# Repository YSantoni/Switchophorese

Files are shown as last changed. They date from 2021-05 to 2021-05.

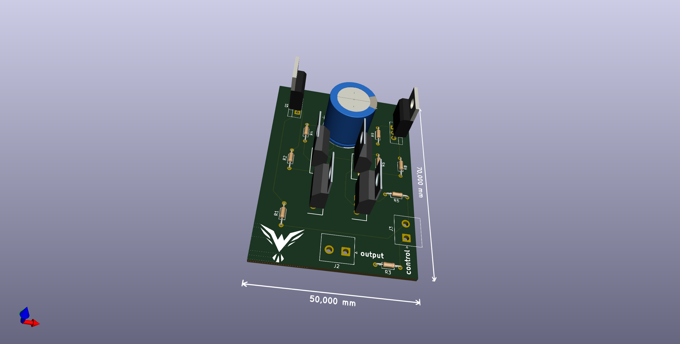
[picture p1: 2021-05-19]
Circuit/FullHBridge/3DFullHBridge.png

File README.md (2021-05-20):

# Switchophorese
An open source Field Inversion Gel Electrophoresis module, programmable via touchscreen.
Connect this module between your classic lab power supply and your gel tray.

This open source laboratory equipment is based on :

- Arduino mega
- Tft 2.8 lcd touch screen shield
- Mosfet full h-bridge circuit

Specs : suitable for gel electrophoresis or field inversion electrophoresis

- 40v to 200v
- max 6.5 amps
- 20ns switching time

Programmable elements :

- pre-heating timer
- runtime timer
- first pulse duration
- last pulse duration
- ratio forward/backward pulse
- linear or exponential time ramp

Libraries used :

https://github.com/prenticedavid/MCUFRIEND_kbv

https://github.com/adafruit/Adafruit_TouchScreen

102794269-6e10de80-43ab-11eb-8156-e7d295066625

group

**First screen** : Welcome screen, touch anywhere to begin.

**Second screen** : Set the duration for the pre-heating timer "Init" and the runtime timer "Run". Select hour, minute, or second and set it with "+" and "-" square, when done touch                 "OK" to go to the next screen.

**Third screen** : Set the duration of the first and last forward pulse of the run (minimum steps of 10ms). Set the duration of the backward pulse as a ratio of the forward pulse.
                You can choose linear or exponential to have the desired evolution of pulse duration during the run.

**Fourth screen** : The recap screen with all the parameters you have entered, when ready press "Begin".

**Fifth screen** : The run screen

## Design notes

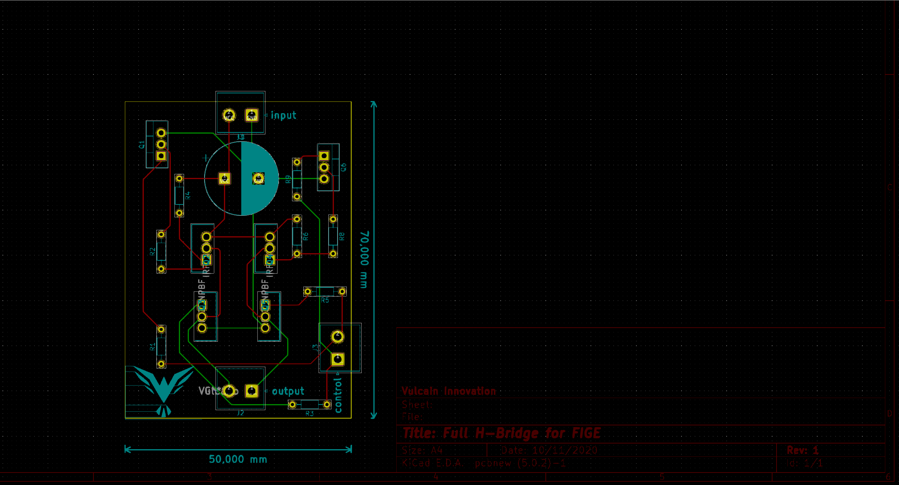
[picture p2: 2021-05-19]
Circuit/FullHBridge/CaptureFullHBridge.PNG

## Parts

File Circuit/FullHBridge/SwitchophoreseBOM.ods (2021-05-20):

Switchophorese FIGE
Total | $0.00
Part Number | Item Description | Number of items | Retailer | Price per item | Price for number of items | Link
1 | Arduino mega 2560 | 1
2 | TFT 2.8 lcd touchscreen shield | 1
3 | 9V DC charger | 1
4 | Electrolytic Capacitor 100uF | 1
5 | Resistor 1K | 2
6 | Resistor 2.2K | 2
7 | Resistor 10K | 2
8 | Resistor 90K | 2
9 | Transistor NPN BJT TIP41 | 2
10 | Transistor MOSFET NPN IRF630 | 2
11 | Transistor MOSFET PNP IRF9630 | 2
12 | Banana plug male (input) | 2
13 | Banana plug female (output) | 2

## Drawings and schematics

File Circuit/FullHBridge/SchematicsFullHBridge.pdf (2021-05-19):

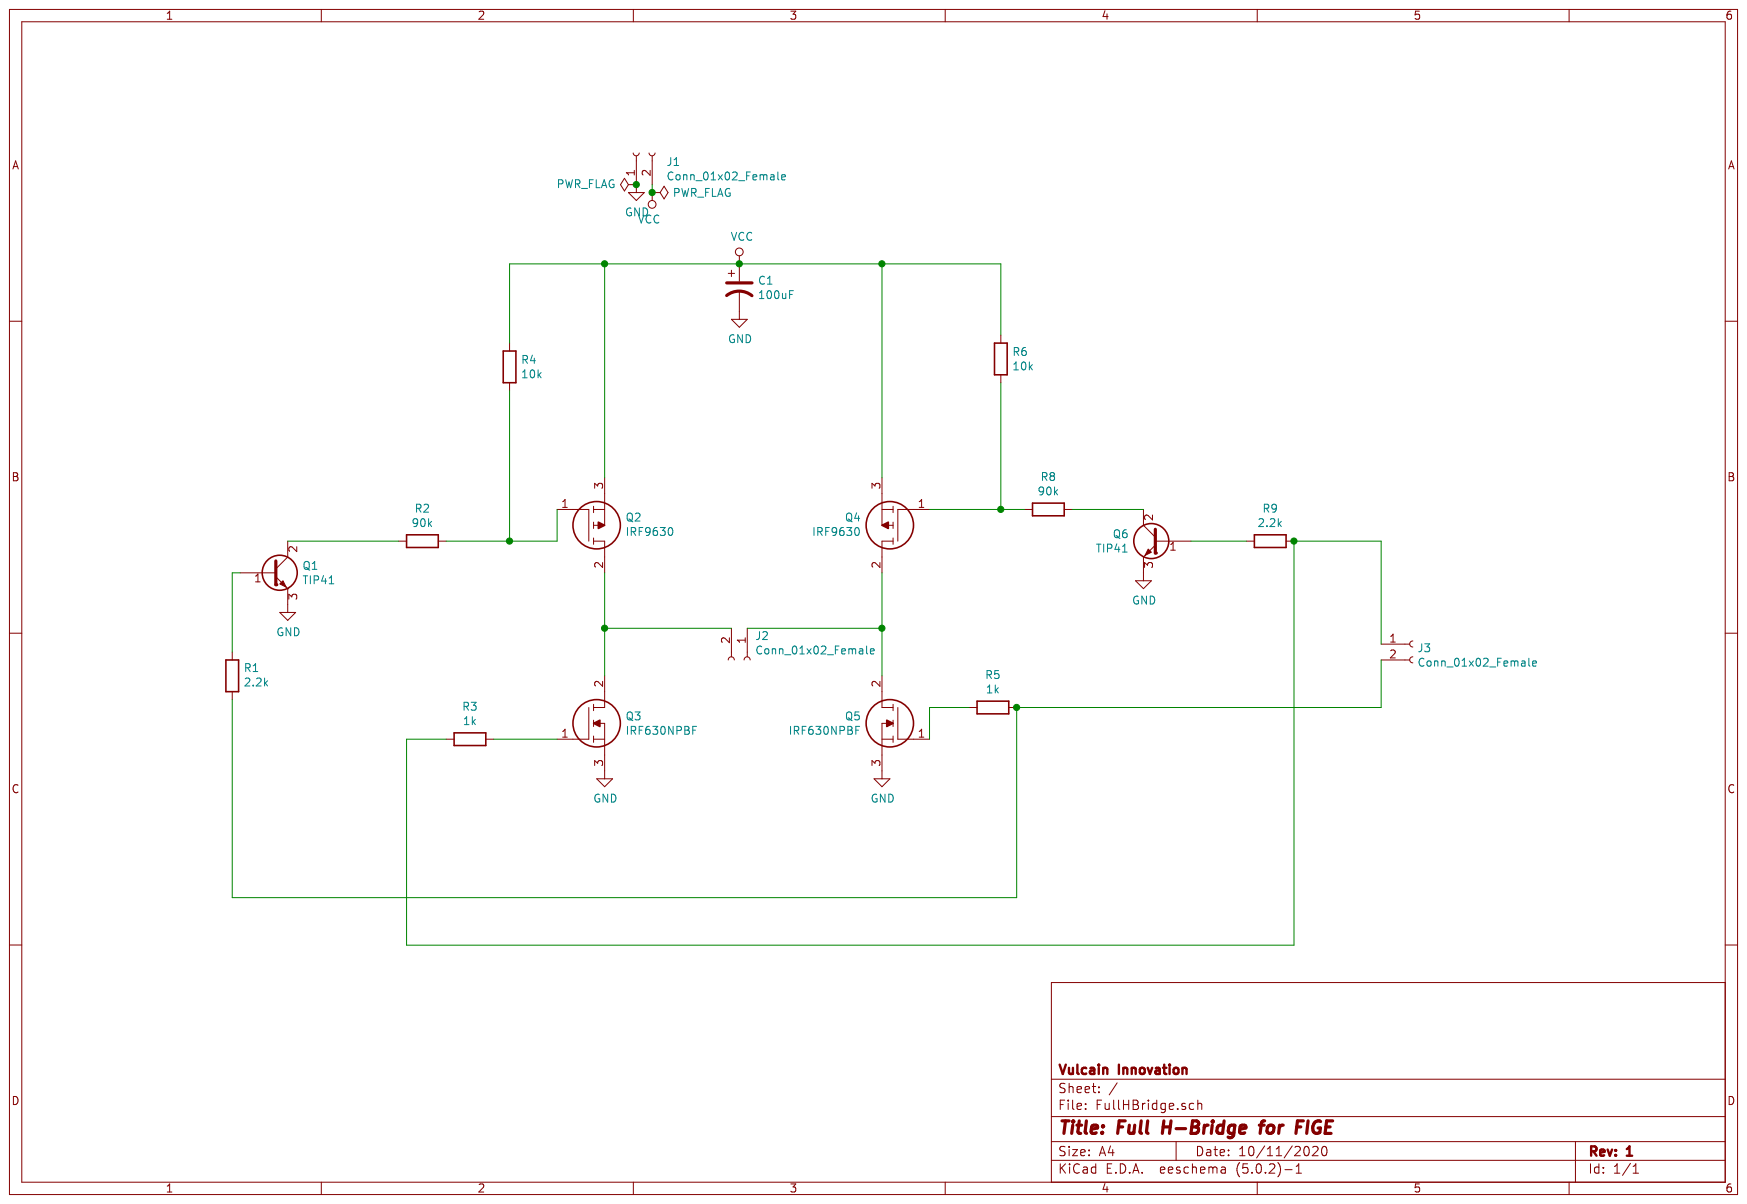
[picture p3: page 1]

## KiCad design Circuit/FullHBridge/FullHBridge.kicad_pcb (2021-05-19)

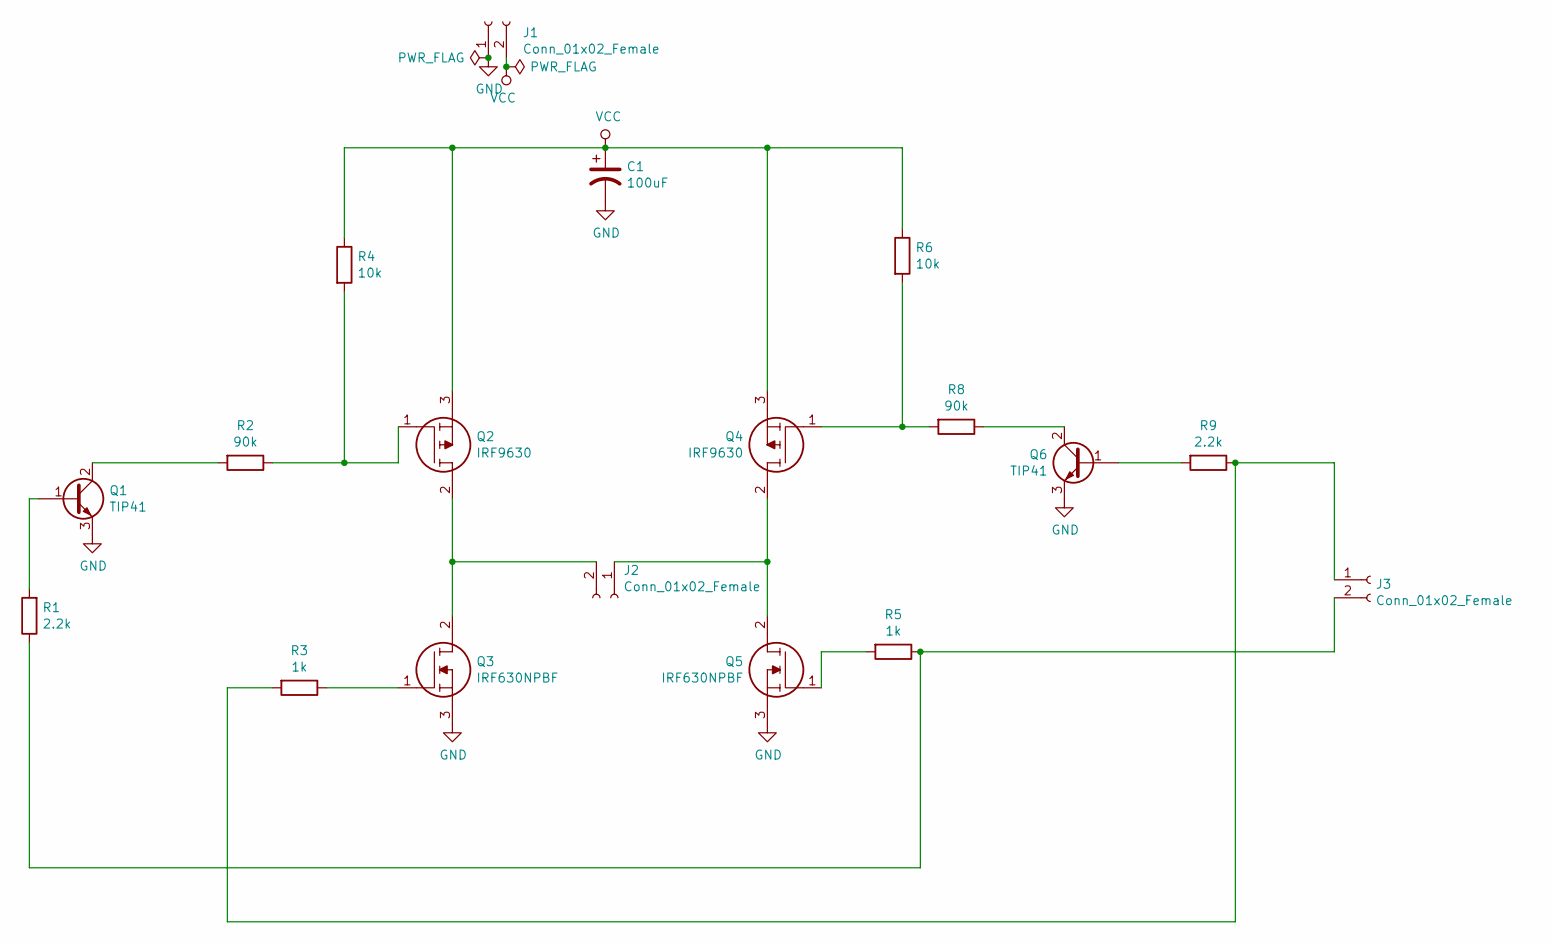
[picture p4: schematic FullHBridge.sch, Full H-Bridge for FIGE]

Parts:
C1: 100uF; CP_Radial_D16.0mm_P7.50mm
J1, J2, J3: Conn_01x02_Female; JST_NV_B02P-NV_1x02_P5.00mm_Vertical
Q1, Q6: TIP41; TO-220-3_Vertical
Q2, Q4: IRF9630; TO254P465X1024X2050-3P; Manufacturer_Part_Number IRF9630; Mouser Part Number 844-IRF9630
Q3, Q5: IRF630NPBF; TO254P469X1042X1967-3P; Manufacturer_Part_Number IRF630NPBF; Mouser Part Number 942-IRF630NPBF
R1, R9: 2.2k; R_Axial_DIN0204_L3.6mm_D1.6mm_P7.62mm_Horizontal
R2, R8: 90k; R_Axial_DIN0204_L3.6mm_D1.6mm_P7.62mm_Horizontal
R3, R5: 1k; R_Axial_DIN0204_L3.6mm_D1.6mm_P7.62mm_Horizontal
R4, R6: 10k; R_Axial_DIN0204_L3.6mm_D1.6mm_P7.62mm_Horizontal

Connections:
GND: C1.2, J1.1, Q1.3 (E), Q3.3, Q5.3, Q6.3 (E)
unnamed: J2.1, Q4.2, Q5.2
unnamed: J2.2, Q2.2, Q3.2
unnamed: J3.1, R3.2, R9.1
unnamed: J3.2, R1.1, R5.1
unnamed: Q1.1 (B), R1.2
unnamed: Q1.2 (C), R2.2
unnamed: Q2.1, R2.1, R4.2
unnamed: Q3.1, R3.1
unnamed: Q4.1, R6.2, R8.2
unnamed: Q5.1, R5.2
unnamed: Q6.1 (B), R9.2
unnamed: Q6.2 (C), R8.1
VCC: C1.1, J1.2, Q2.3, Q4.3, R4.1, R6.1

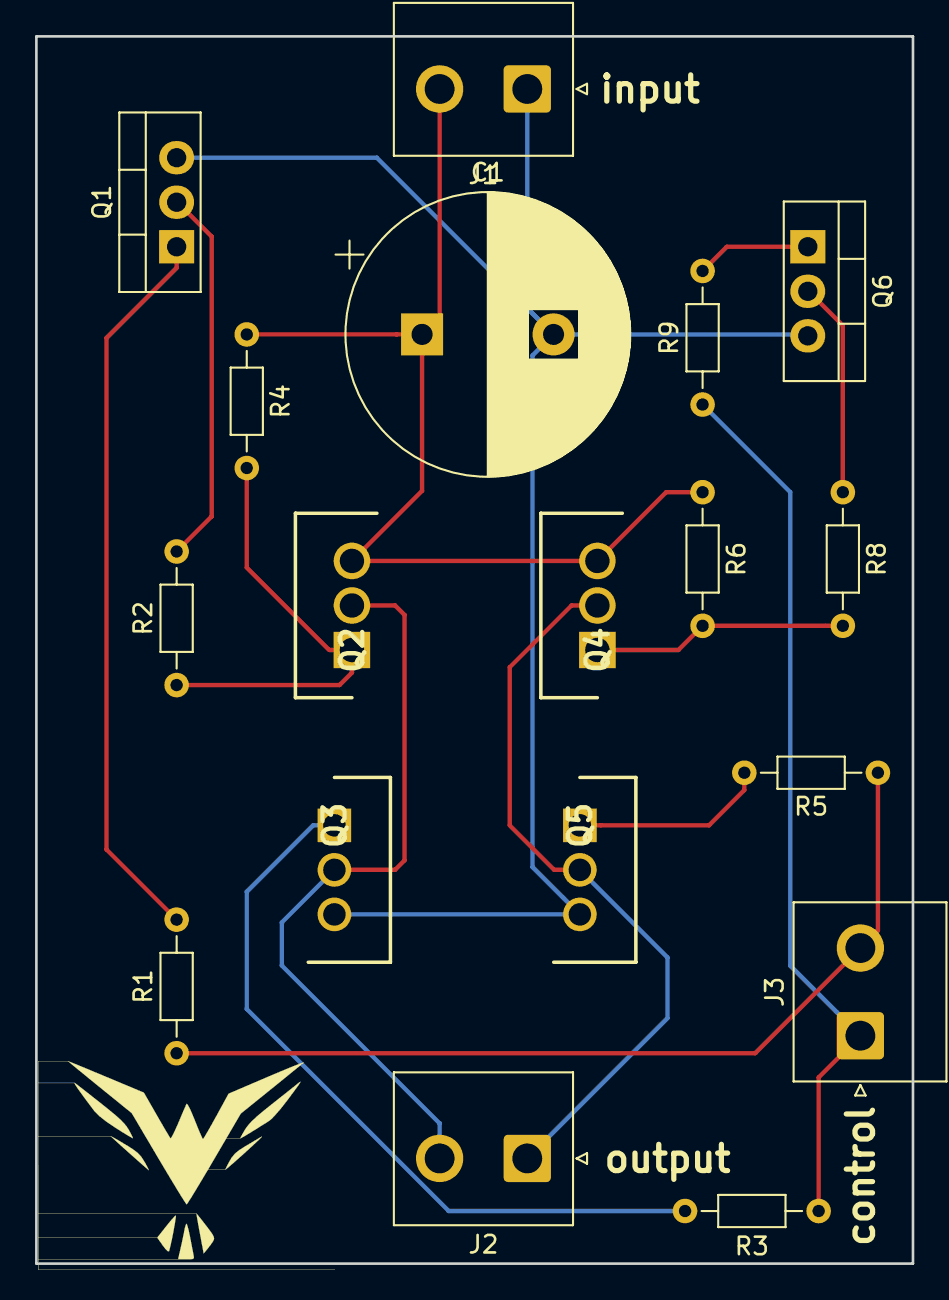
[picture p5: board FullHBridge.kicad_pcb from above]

Board: 2 copper layers, 50.0 x 70.0 mm, 18 parts (0 on the bottom side), 14 nets.

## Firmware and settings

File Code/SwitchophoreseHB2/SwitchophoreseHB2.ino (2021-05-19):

//VULCAIN INNOVATION
//06/11/2020

#include <MCUFRIEND_kbv.h>
MCUFRIEND_kbv tft;       
#include <TouchScreen.h>
#include "bitmaps.h"

#if defined(__SAM3X8E__)
#undef __FlashStringHelper::F(string_literal)
#define F(string_literal) string_literal
#endif

uint8_t YP = A2;  // must be an analog pin
uint8_t XM = A3;  // must be an analog pin
uint8_t YM = 8;   // can be a digital pin
uint8_t XP = 9;   // can be a digital pin
uint8_t SwapXY = 0;

uint16_t TS_LEFT = 920;
uint16_t TS_RT  = 150;
uint16_t TS_TOP = 940;
uint16_t TS_BOT = 120;
char *name = "Unknown controller";

// For better pressure precision, we need to know the resistance
// between X+ and X- Use any multimeter to read it
// For the one we're using, its 560 ohms across the X plate
TouchScreen ts = TouchScreen(XP, YP, XM, YM, 560);
TSPoint tp;

#define MINPRESSURE 10
#define MAXPRESSURE 1000

#define SWAP(a, b) {uint16_t tmp = a; a = b; b = tmp;}

int16_t BOXSIZE;
int16_t PENRADIUS = 3;
uint16_t identifier, oldcolor, currentcolor;
uint8_t Orientation = 1;    //Landscape

// Assign human-readable names to some common (and less common) 16-bit color values:
#define TEST 0xff9effde 
#define ALICEBLUE 0xF7DF
#define ANTIQUEWHITE 0xFF5A
#define AQUA 0x07FF
#define AQUAMARINE 0x7FFA
#define AZURE 0xF7FF
#define BEIGE 0xF7BB
#define BISQUE 0xFF38
#define BLACK 0x0000
#define BLANCHEDALMOND 0xFF59
#define BLUE 0x001F
#define BLUEVIOLET 0x895C
#define BROWN 0xA145
#define BURLYWOOD 0xDDD0
#define CADETBLUE 0x5CF4
#define CHARTREUSE 0x7FE0
#define CHOCOLATE 0xD343
#define CORAL 0xFBEA
#define CORNFLOWERBLUE 0x64BD
#define CORNSILK 0xFFDB
#define CRIMSON 0xD8A7
#define CYAN 0x07FF
#define DARKBLUE 0x0011
#define DARKCYAN 0x0451
#define DARKGOLDENROD 0xBC21
#define DARKGREY 0xAD55
#define DARKGREEN 0x0320
#define DARKKHAKI 0xBDAD
#define DARKMAGENTA 0x8811
#define DARKOLIVEGREEN 0x5345
#define DARKORANGE 0xFC60
#define DARKORCHID 0x9999
#define DARKRED 0x8800
#define DARKSALMON 0xECAF
#define DARKSEAGREEN 0x8DF1
#define DARKSLATEBLUE 0x49F1
#define DARKSLATEGREY 0x2A69
#define DARKTURQUOISE 0x067A
#define DARKVIOLET 0x901A
#define DEEPPINK 0xF8B2
#define DEEPSKYBLUE 0x05FF
#define DIMGREY 0x6B4D
#define DODGERBLUE 0x1C9F
#define FIREBRICK 0xB104
#define FLORALWHITE 0xFFDE
#define FORESTGREEN 0x2444
#define FUCHSIA 0xF81F
#define GAINSBORO 0xDEFB
#define GHOSTWHITE 0xFFDF
#define GOLD 0xFEA0
#define GOLDENROD 0xDD24
#define GREY 0x8410
#define GREEN 0x0400
#define GREENYELLOW 0xAFE5
#define HONEYDEW 0xF7FE
#define HOTPINK 0xFB56
#define INDIANRED 0xCAEB
#define INDIGO 0x4810
#define IVORY 0xFFFE
#define KHAKI 0xF731
#define LAVENDER 0xE73F
#define LAVENDERBLUSH 0xFF9E
#define LAWNGREEN 0x7FE0
#define LEMONCHIFFON 0xFFD9
#define LIGHTBLUE 0xAEDC
#define LIGHTCORAL 0xF410
#define LIGHTCYAN 0xE7FF
#define LIGHTGOLDENRODYELLOW 0xFFDA
#define LIGHTGREEN 0x9772
#define LIGHTGREY 0xD69A
#define LIGHTPINK 0xFDB8
#define LIGHTSALMON 0xFD0F
#define LIGHTSEAGREEN 0x2595
#define LIGHTSKYBLUE 0x867F
#define LIGHTSLATEGREY 0x7453
#define LIGHTSTEELBLUE 0xB63B
#define LIGHTYELLOW 0xFFFC
#define LIME 0x07E0
#define LIMEGREEN 0x3666
#define LINEN 0xFF9C
#define MAGENTA 0xF81F
#define MAROON 0x8000
#define MEDIUMAQUAMARINE 0x6675
#define MEDIUMBLUE 0x0019
#define MEDIUMORCHID 0xBABA
#define MEDIUMPURPLE 0x939B
#define MEDIUMSEAGREEN 0x3D8E
#define MEDIUMSLATEBLUE 0x7B5D
#define MEDIUMSPRINGGREEN 0x07D3
#define MEDIUMTURQUOISE 0x4E99
#define MEDIUMVIOLETRED 0xC0B0
#define MIDNIGHTBLUE 0x18CE
#define MINTCREAM 0xF7FF
#define MISTYROSE 0xFF3C
#define MOCCASIN 0xFF36
#define NAVAJOWHITE 0xFEF5
#define NAVY 0x0010
#define OLDLACE 0xFFBC
#define OLIVE 0x8400
#define OLIVEDRAB 0x6C64
#define ORANGE 0xFD20
#define ORANGERED 0xFA20
#define ORCHID 0xDB9A
#define PALEGOLDENROD 0xEF55
#define PALEGREEN 0x9FD3
#define PALETURQUOISE 0xAF7D
#define PALEVIOLETRED 0xDB92
#define PAPAYAWHIP 0xFF7A
#define PEACHPUFF 0xFED7
#define PERU 0xCC27
#define PINK 0xFE19
#define PLUM 0xDD1B
#define POWDERBLUE 0xB71C
#define PURPLE 0x8010
#define RED 0xF800
#define ROSYBROWN 0xBC71
#define ROYALBLUE 0x435C
#define SADDLEBROWN 0x8A22
#define SALMON 0xFC0E
#define SANDYBROWN 0xF52C
#define SEAGREEN 0x2C4A
#define SEASHELL 0xFFBD
#define SIENNA 0xA285
#define SILVER 0xC618
#define SKYBLUE 0x867D
#define SLATEBLUE 0x6AD9
#define SLATEGREY 0x7412
#define SNOW 0xFFDF
#define SPRINGGREEN 0x07EF
#define STEELBLUE 0x4416
#define TAN 0xD5B1
#define TEAL 0x0410
#define THISTLE 0xDDFB
#define TOMATO 0xFB08
#define TURQUOISE 0x471A
#define VIOLET 0xEC1D
#define WHEAT 0xF6F6
#define WHITE 0xFFFF
#define WHITESMOKE 0xF7BE
#define YELLOW 0xFFE0
#define YELLOWGREEN 0x9E66

//////////////////////////////////////////////////////////////////////////////////////////// Defining variables
int currentPage=0; // navigation


unsigned long initSec = 1; // initial timer
unsigned long initMin = 0;
unsigned long initHour = 0;

unsigned long runSec = 0;// run time
unsigned long runMin = 0;
unsigned long runHour = 0;

int fPulseSec = 0; //first pulse
int fPulseMilliSec = 0;

int lPulseSec = 0; // last pulse
int lPulseMilliSec = 0;

int ratio = 50; // Ratio pulse back

bool linear = true; //touch icons
bool expo = false;
bool ok = false;
bool back = false;
bool Start = false;
bool pause = true;


int Init = 0; // id of boxes on initscreen
int Pulse = 0;

//////////////////////////////////////////////////////////////////////////////////////////// Setup
void setup(void)
{
    uint16_t tmp;
    tft.begin(9600);

    tft.reset();
    identifier = tft.readID();
   
    if (0) {
   
    } else if (identifier == 0x9341) {
        name = "ILI9341 BLUE";
        TS_LEFT = 917; TS_RT = 125; TS_TOP = 126; TS_BOT = 950;
        SwapXY = 1;
       
    }
    else {
        name = "unknown";
    }
    switch (Orientation) {      // adjust for different aspects
        case 0:   break;        //no change,  calibrated for PORTRAIT
        case 1:   tmp = TS_LEFT, TS_LEFT = TS_BOT, TS_BOT = TS_RT, TS_RT = TS_TOP, TS_TOP = tmp;  break;
        case 2:   SWAP(TS_LEFT, TS_RT);  SWAP(TS_TOP, TS_BOT); break;
        case 3:   tmp = TS_LEFT, TS_LEFT = TS_TOP, TS_TOP = TS_RT, TS_RT = TS_BOT, TS_BOT = tmp;  break;
    }

    Serial.begin(9600);
    ts = TouchScreen(XP, YP, XM, YM, 300);     //call the constructor AGAIN with new values.
    tft.begin(identifier);    
    tft.setRotation(Orientation);
   // tft.fillScreen(BLACK);


}  
//////////////////////////////////////////////////////////////////////////////////////////// Loop   
void loop()
{
//=========================== welcome Screen ========================= //
  
  if (currentPage==0){

    welcome_screen();
     while(currentPage==0){
       tp = ts.getPoint();
        pinMode(XM, OUTPUT);
        pinMode(YP, OUTPUT);
        pinMode(XP, OUTPUT);
        pinMode(YM, OUTPUT);
      if (tp.z < MINPRESSURE || tp.z > MAXPRESSURE) continue;
      
      if (tp.x > 450 && tp.x < 570  && tp.y > 450 && tp.y < 570)
      currentPage=1; 
     
      }
  }

//=========================== Init Screen ========================= //
if (currentPage==1){

    init_screen();
     
      while(currentPage==1){
        
        tp = ts.getPoint();
        pinMode(XM, OUTPUT);
        pinMode(YP, OUTPUT);
        pinMode(XP, OUTPUT);
        pinMode(YM, OUTPUT);
        
     if (tp.z < MINPRESSURE || tp.z > MAXPRESSURE) continue;
     
     if (tp.x > 180 && tp.x < 360  && tp.y > 310 && tp.y < 530)
        drawFrameRED("+");
      
     if (tp.x > 180 && tp.x < 360  && tp.y > 580 && tp.y < 800)
        drawFrameRED("-");

// selection paramètres

   
     if ( tp.x > 380 && tp.x < 500 && tp.y > 590 && tp.y < 730)//init seconds
        Init = 1;
        if ( Init == 1)
           {
                if (tp.x > 180 && tp.x < 360  && tp.y > 580 && tp.y < 800 && initSec < 59)// + button
                {initSec=initSec+1;
                drawFrameRED("+");}
                else if (tp.x > 180 && tp.x < 360  && tp.y > 310 && tp.y < 530 && initSec > 0)// - button
                {initSec=initSec-1;
                drawFrameRED("-");}
                //delay(10);

                tft.drawRect(170, tft.height()/4, BOXSIZE, BOXSIZE - 10, BLACK);
                tft.fillRect(170, tft.height()/4, BOXSIZE, BOXSIZE - 10, BLACK);
                
                tft.setCursor(176, 68);
                tft.setTextSize(3);
                tft.setTextColor(YELLOW);
                tft.print(initSec);}
         
          
           
     if ( tp.x > 530 && tp.x < 650 && tp.y > 590 && tp.y < 730)//init minutes
       Init = 2;
        if ( Init == 2)
              {                
                if (tp.x > 180 && tp.x < 360  && tp.y > 580 && tp.y < 800 && initMin < 59)// + button
                {initMin=initMin+1;}
                else if (tp.x > 180 && tp.x < 360  && tp.y > 310 && tp.y < 530 && initMin > 0)// - button
                {initMin=initMin-1;}
                  delay(10);
                                  
                tft.drawRect(110, tft.height()/4, BOXSIZE, BOXSIZE - 10, BLACK);
                tft.fillRect(110, tft.height()/4, BOXSIZE, BOXSIZE - 10, BLACK);
                
                tft.setCursor(116, 68);
                tft.setTextSize(3);
                tft.setTextColor(YELLOW);
                tft.print(initMin);}


     
     if ( tp.x > 690 && tp.x < 800 && tp.y > 590 && tp.y < 730)//init hours
       Init = 3;
        if ( Init == 3)
              {                
                if (tp.x > 180 && tp.x < 360  && tp.y > 580 && tp.y < 800 )// + button
                {initHour=initHour+1;}
                else if (tp.x > 180 && tp.x < 360  && tp.y > 310 && tp.y < 530 && initHour > 0)// - button
                {initHour=initHour-1;}
                  delay(10);
                                  
                tft.drawRect(50, tft.height()/4, BOXSIZE, BOXSIZE - 10, BLACK);
                tft.fillRect(50, tft.height()/4, BOXSIZE, BOXSIZE - 10, BLACK);
                tft.setCursor(56, 68);
                tft.setTextSize(3);
                tft.setTextColor(YELLOW);
                tft.print(initHour);}


                
                
       if ( tp.x > 380 && tp.x < 500 && tp.y > 320 && tp.y < 360)//Run seconds
        Init = 4;
        if ( Init == 4)
           {
                if (tp.x > 180 && tp.x < 360  && tp.y > 580 && tp.y < 800 && runSec < 59)// + button
                {runSec=runSec+1;
                drawFrameRED("+");}
                else if (tp.x > 180 && tp.x < 360  && tp.y > 310 && tp.y < 530 && runSec > 0)// - button
                {runSec=runSec-1;
                drawFrameRED("-");}
                //  delay(10);

                tft.drawRect(170, ((tft.height()*2)/3)-20, BOXSIZE, BOXSIZE - 10, BLACK);
                tft.fillRect(170, ((tft.height()*2)/3)-20, BOXSIZE, BOXSIZE - 10, BLACK);
                 
                 tft.setCursor(176, 148);
                 tft.setTextSize(3);
                 tft.setTextColor(YELLOW);
                 tft.print(runSec);
              } 

           if ( tp.x > 530 && tp.x < 650 && tp.y > 320 && tp.y < 370)//Run minutes
            Init = 5;
             if ( Init == 5)
              {                
                if (tp.x > 180 && tp.x < 360  && tp.y > 580 && tp.y < 800 && runMin < 59)// + button
                {runMin=runMin+1;}
                else if (tp.x > 180 && tp.x < 360  && tp.y > 310 && tp.y < 530 && runMin > 0)// - button
                {runMin=runMin-1;}
                  delay(10);
                                  
                tft.drawRect(110, ((tft.height()*2)/3)-20, BOXSIZE, BOXSIZE - 10, BLACK);
                tft.fillRect(110, ((tft.height()*2)/3)-20, BOXSIZE, BOXSIZE - 10, BLACK);
    
                tft.setCursor(116, 148);
                tft.setTextSize(3); 
                tft.setTextColor(YELLOW);
                tft.print(runMin);}


           if ( tp.x > 690 && tp.x < 800 && tp.y > 320 && tp.y < 370)//Run hours
            Init = 6;
             if ( Init == 6)
              {                
                if (tp.x > 180 && tp.x < 360  && tp.y > 580 && tp.y < 800 && runHour < 99)// + button
                {runHour=runHour+1;}
                else if (tp.x > 180 && tp.x < 360  && tp.y > 310 && tp.y < 530 && runHour > 0)// - button
                {runHour=runHour-1;}
                  delay(10);
                                  
                tft.drawRect(50, ((tft.height()*2)/3)-20, BOXSIZE, BOXSIZE - 10, BLACK);
                tft.fillRect(50, ((tft.height()*2)/3)-20, BOXSIZE, BOXSIZE - 10, BLACK);
                tft.setCursor(56, 148);
                tft.setTextSize(3); 
                tft.setTextColor(YELLOW);
                tft.print(runHour);}
                
      if (tp.x > 120 && tp.x < 250  && tp.y > 130 && tp.y < 250)
        currentPage=2;
       
      }
    
}     
//fin selection paramètres 

//============================ Pulse screen ========================== //

if (currentPage==2){
    pulse_screen(linear,expo);
        
    while(currentPage==2){
      tp = ts.getPoint();
        pinMode(XM, OUTPUT);
        pinMode(YP, OUTPUT);
        pinMode(XP, OUTPUT);
        pinMode(YM, OUTPUT);

      if (tp.z < MINPRESSURE || tp.z > MAXPRESSURE) continue;
      if (tp.x > 180 && tp.x < 360  && tp.y > 310 && tp.y < 530)
        drawFrameRED("+");
      
      if (tp.x > 180 && tp.x < 360  && tp.y > 580 && tp.y < 800)
        drawFrameRED("-");
// sélection paramètres

      if ( tp.x > 490 && tp.x < 620 && tp.y > 710 && tp.y < 820)//First pulse Milliseconds
        Pulse = 1;
        if ( Pulse == 1)
           {
                if (tp.x > 180 && tp.x < 360  && tp.y > 580 && tp.y < 800 && fPulseMilliSec < 99)// + button
                {fPulseMilliSec=fPulseMilliSec+1;
                drawFrameRED("+");}
                else if (tp.x > 180 && tp.x < 360  && tp.y > 310 && tp.y < 530 && fPulseMilliSec > 0)// - button
                {fPulseMilliSec=fPulseMilliSec-1;
                drawFrameRED("-");}
                  //delay(5);

                 tft.drawRect(130, (tft.height()/5)-20, BOXSIZE+10, BOXSIZE - 10, BLACK);
                 tft.fillRect(130, (tft.height()/5)-20, BOXSIZE+10, BOXSIZE - 10, BLACK);
    
                 tft.setCursor(136, 36);
                 tft.setTextSize(3); 
                 tft.setTextColor(YELLOW);
                 tft.print(fPulseMilliSec);}

      if ( tp.x > 680 && tp.x < 810 && tp.y > 710 && tp.y < 820)//First pulse secondes
        Pulse = 2;
        if ( Pulse == 2)
           {
                if (tp.x > 180 && tp.x < 360  && tp.y > 580 && tp.y < 800)// + button
                {fPulseSec=fPulseSec+1;
                drawFrameRED("+");}
                else if (tp.x > 180 && tp.x < 360  && tp.y > 310 && tp.y < 530 && fPulseSec > 0)// - button
                {fPulseSec=fPulseSec-1;
                drawFrameRED("-");}
                  //delay(5);

                 tft.drawRect(66, (tft.height()/5)-20, BOXSIZE+10, BOXSIZE - 10, BLACK);
                 tft.fillRect(66, (tft.height()/5)-20, BOXSIZE+10, BOXSIZE - 10, BLACK);
                 
                 tft.setCursor(70, 36);
                 tft.setTextSize(3); 
                 tft.setTextColor(YELLOW);
                 tft.print(fPulseSec);}

      if ( tp.x > 490 && tp.x < 620 && tp.y > 540 && tp.y < 660)//Last pulse milliseconds
        Pulse = 3;
        if ( Pulse == 3)
           {
                if (tp.x > 180 && tp.x < 360  && tp.y > 580 && tp.y < 800 && lPulseMilliSec < 99)// + button
                {lPulseMilliSec=lPulseMilliSec+1;
                drawFrameRED("+");}
                else if (tp.x > 180 && tp.x < 360  && tp.y > 310 && tp.y < 530 && lPulseMilliSec > 0)// - button
                {lPulseMilliSec=lPulseMilliSec-1;
                drawFrameRED("-");}
                  //delay(5);

                 tft.drawRect(130, ((tft.height()*2)/5)-20, BOXSIZE, BOXSIZE - 10, BLACK);
                 tft.fillRect(130, ((tft.height()*2)/5)-20, BOXSIZE, BOXSIZE - 10, BLACK);
                 tft.setCursor(136, 84);
                 tft.setTextSize(3);
                 tft.setTextColor(YELLOW);
                  tft.print(lPulseMilliSec);}

      
      if ( tp.x > 680 && tp.x < 810 && tp.y > 540 && tp.y < 660)//Last pulse secondes
        Pulse = 4;
        if ( Pulse == 4)
           {
                if (tp.x > 180 && tp.x < 360  && tp.y > 580 && tp.y < 800)// + button
                {lPulseSec=lPulseSec+1;
                drawFrameRED("+");}
                else if (tp.x > 180 && tp.x < 360  && tp.y > 310 && tp.y < 530 && lPulseSec > 0)// - button
                {lPulseSec=lPulseSec-1;
                drawFrameRED("-");}
                  //delay(5);

                  tft.drawRect(66, ((tft.height()*2)/5)-20, BOXSIZE+10, BOXSIZE - 10, BLACK);
                  tft.fillRect(66, ((tft.height()*2)/5)-20, BOXSIZE+10, BOXSIZE - 10, BLACK);
                  tft.setCursor(70, 84);
                  tft.setTextSize(3); 
                  tft.setTextColor(YELLOW);
                  tft.print(lPulseSec);}



      if ( tp.x > 580 && tp.x < 700 && tp.y > 380 && tp.y < 500)//Ratio pulse back
        Pulse = 5;
        if ( Pulse == 5)
           {
                if (tp.x > 180 && tp.x < 360  && tp.y > 580 && tp.y < 800 && ratio < 100)// + button
                {ratio=ratio+1;
                drawFrameRED("+");}
                else if (tp.x > 180 && tp.x < 360  && tp.y > 310 && tp.y < 530 && ratio > 0)// - button
                {ratio=ratio-1;
                drawFrameRED("-");}
                  //delay(5);

                 tft.drawRect(96, ((tft.height()*3)/5)-20, BOXSIZE+8, BOXSIZE - 10, BLACK);
                 tft.fillRect(96, ((tft.height()*3)/5)-20, BOXSIZE+8, BOXSIZE - 10, BLACK);
                 tft.setCursor(100, 132);
                 tft.setTextSize(3); 
                 tft.setTextColor(YELLOW);
                  tft.print(ratio);}

       
        if ( tp.x > 680 && tp.x < 990 && tp.y > 110 && tp.y < 250 )//Linear time ramp
              
              Pulse = 6;
              int L=100;
              int H=40;
               if ( Pulse == 6)
               { linear = true;                  
                  expo = false;
                  tft.drawRoundRect(117, 192, L-4, H-4, 8, BLACK);
                  tft.setCursor( 140, 202);
                  tft.setTextSize(2);
                   tft.setTextColor(AQUAMARINE);
                    tft.print("expo");
                    
                  tft.drawRoundRect(10, 192, L-4, H-4, 8, FUCHSIA);
                 tft.setCursor( 22, 202);
                 tft.setTextSize(2);
                  tft.setTextColor(FUCHSIA);
                    tft.print("linear");
                 delay(10);}
               
               

         if ( tp.x > 350 && tp.x < 650 && tp.y > 110 && tp.y < 250 )//exponential time ramp
             
              Pulse = 7;
              
               if ( Pulse == 7)
               { expo = true;
                 linear = false;

                 tft.drawRoundRect(10, 192, L-4, H-4, 8, AQUAMARINE);
                 tft.setCursor( 22, 202);
                 tft.setTextSize(2);
                  tft.setTextColor(AQUAMARINE);
                    tft.print("linear");
                    
                 tft.drawRoundRect(117, 192, L-4, H-4, 8, FUCHSIA);
                 tft.setCursor( 140, 202);
                 tft.setTextSize(2);
                  tft.setTextColor(FUCHSIA);
                    tft.print("expo");
                 delay(10);}
                 
               


// Fin selection paramètres

      if (tp.x > 120 && tp.x < 250  && tp.y > 830 && tp.y < 905)
        currentPage=1;
                    
      if (tp.x > 120 && tp.x < 250  && tp.y > 130 && tp.y < 250)
        currentPage=3;
    
    }
}

 //============================ Recap screen ========================== //   

if (currentPage==3){
    recap_screen(linear);

    while(currentPage==3){
      tp = ts.getPoint();
        pinMode(XM, OUTPUT);
        pinMode(YP, OUTPUT);
        pinMode(XP, OUTPUT);
        pinMode(YM, OUTPUT);

      if (tp.z < MINPRESSURE || tp.z > MAXPRESSURE) continue;

    
      if (tp.x > 120 && tp.x < 250  && tp.y > 830 && tp.y < 905)
        currentPage=2;
        
      if (tp.x > 120 && tp.x < 330  && tp.y > 110 && tp.y < 250)
        currentPage=4;
      }

}
//============================ Run screen ========================== //

if (currentPage==4){
        
int positive = 38;
int negative = 34;
int32_t previousMillis = 0;
int32_t currentMillis = 0;  

bool isTimer = true;
unsigned long pauseTime = 0;
unsigned long pauserun = 0;
unsigned long elapsedInitTime = 0;
unsigned long elapsedRunTime = 0;
unsigned long pauseInitStart = 0;
unsigned long pauseInitEnd = 0;
unsigned long startRun =0;
unsigned long startInit =0;
unsigned long runMillis = 0;
unsigned long pauseRunStart = 0;
unsigned long pauseRunEnd = 0;
unsigned long pulseMillis = 0;
unsigned long previousfPulseMillis=0; //initilized to start on positive pulse
unsigned long firstMillis = 0;
unsigned long pulsebMillis = 0;

unsigned long previousbPulseMillis=0;

long runTimer = runSec*1000+runMin*60000+runHour*3600000; // en millisecondes; // running screen

long Tsf = fPulseSec * 1000 + fPulseMilliSec * 10; // Total forward pulse
long Tsb = Tsf*ratio/100; // Total backward pulse
long Tef = lPulseSec * 1000 + lPulseMilliSec * 10; // Total forward pulse
long Teb = Tef*ratio/100; // Total backward pulse
long Ts=Tsf+Tsb; // Total start f+b pulses
long Te=Tef+Teb; // Total end f+b pulses


// linear equation
long nbPulse = 2*runTimer/(Ts+Te);
long increment = (Te-Ts)/(nbPulse-1);

// exponential equation
long incrementExpo = (runTimer - Ts)*(runTimer - Te);
long nbPulseExpo = log(Te/Ts)+1;
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

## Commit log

2021-05-19 Create Switchophorese
2021-05-19 Create Kicad
2021-05-20 Create 3D printing
2021-05-20 Add files via upload
    Prices and retailers remain to be added
    [SwitchophoreseBOM.ods]
